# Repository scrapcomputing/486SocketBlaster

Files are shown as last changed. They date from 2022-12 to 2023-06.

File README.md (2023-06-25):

# 486SocketBlaster

486SocketBlaster is a simple voltage adapter for 486 processors. It allows you
to use a 3-volt 486 CPU on an older 5-volt-only motherboard. For example you
can use a DX4 or an Am5x86 on an old 486 motherboard that would normally only
work with 5-volt CPUs. This basically converts any 3-volt CPU to an "Overdrive".

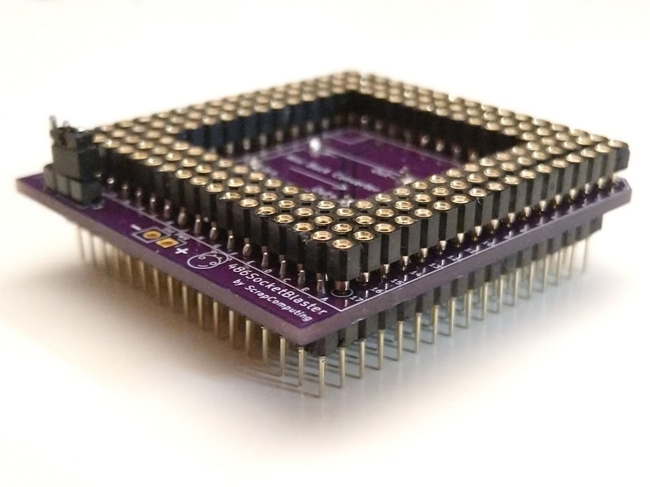
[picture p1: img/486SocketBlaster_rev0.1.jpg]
486SocketBlaster Rev0.1 on a purple PCB


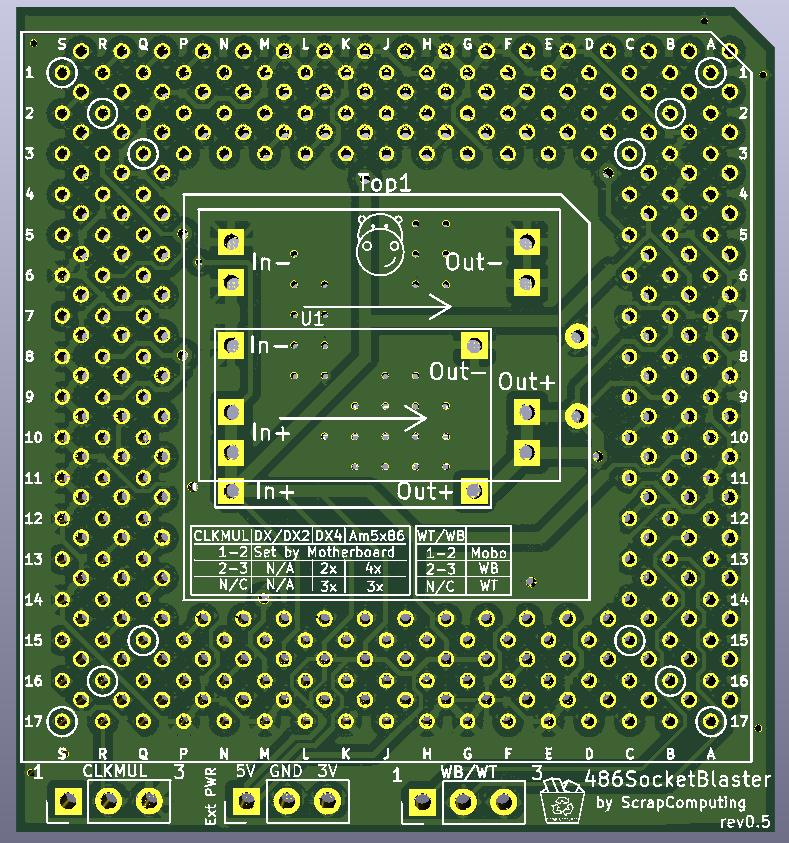
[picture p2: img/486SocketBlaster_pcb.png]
486SocketBlaster PCB


# How does it work ?

It is really simple: All CPU pins are passed through to the motherboard socket,
except for the Vcc. Those are connected to the output of a mini buck converter
that can be soldered to the 486SocketBlaster board.

# Soldering/Assembly Instructions

This board is not the easiest thing to solder, but can be done with a standard
soldering iron and some patience.
The best way to solder the headers is to start with the innermost one and work
outwards in a spiral manner alternating between the top and bottom side as
needed (see image below). This way you only work on the outside and can easily
reach all the pins.

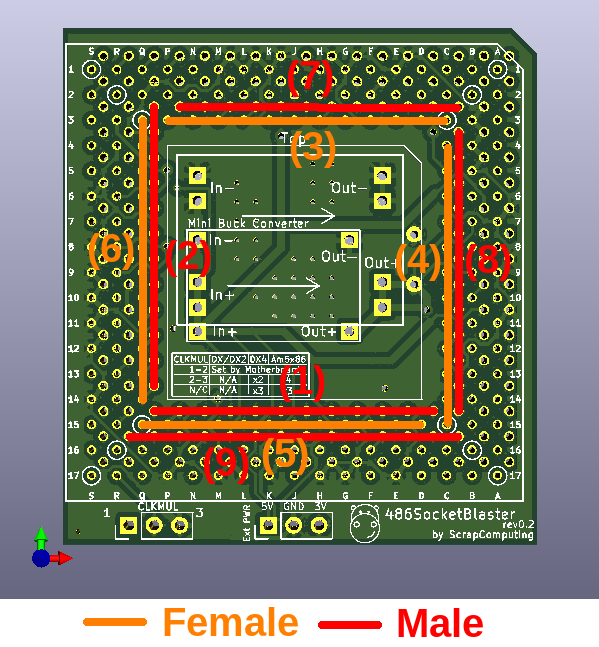
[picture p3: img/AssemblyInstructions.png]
Assembly Instructions


A desoldering gun may be useful when you accidentally clog up other holes. But
it is probably best to be very careful and avoid clogging them in the first
place. Also using flux makes it easier.

Please make sure you check the solder joints (also check for continuity) before
you add another row of headers on the same side, because the new row will
permanently block your access to the solder joints!
Desoldering a header is almost impossible even with a desoldering gun due to the
very tight hole tolerances.
So it has to be soldered correctly from the first try.

# Voltage regulator

The 486SocketBlaster can be powered by a cheap of-the-shelf buck converter, or
by an external one. The circuit board accepts two common types of small voltage
buck converters, usually found using keywords like "mini buck converter".
These are commonly rated at up to 3A of current. Given that 3-volt 486 CPUs are
usually very efficient (the DX4-100 is rated at max 3.55/5.22W typical/max) such
a regulator should be adequate in most cases.
For best stability try to source a good quality part.

If you are planning to overclock or to use a more power hungry CPU, please use an external regulation circuit plugged in to the `ExtPwr` header, or use a *very* good quality mini buck converter.

# WARNING!!!

Please make sure you know what you are doing!
Improper assembly/settings/use can damage both your precious motherboard and your precious CPU!

# Features

- External Power Header. This can be used either for monitoring the CPU voltage, or for providing power externally, either with an external power supply or an external voltage regulator.
- CLKMUL Header for selecting/overriding the CPU multiplier. This controls CPU pin `R17`. 1-2 connects it to the motherboard socket pin and 2-3 connects it to ground. This reduces the multiplier of a DX4 to 2x (66MHz) and sets the multiplier of an Am5x86 to 4x (133MHz).
- WB/WT Header for selecting/overriding Write-Back/Write-Through cache. This controls processor CPU pin `B13` (which is the `CLKMUL` pin in earlier 486 CPUs). 1-2 connects it to the motherboard socket pin, and 2-3 connects it to Vcc, which enables Write-Back.

# Bill of materials

Item                            | ##  | Description
--------------------------------|-----|--------------------------------------------------------
mini buck converter             | 1   | We support two common sizes: 22x17mm and 18x12mm. These usually have chips like MP1584, MP2307 and others
40pin SIP pin header (male)     | 5   | Single-row round pin 2.54mm pitch (male). Socket pin diameter: 0.50mm, PCB pin diameter: 0.60mm. (see photo below)
40pin SIP socket header (female)| 5   | Single-row round pin sockets, 2.54mm pitch. PCB pin diameter: 0.55mm. (see photo below) 
SMD Ceramic Capacitors          | 4   | 10uF SMD 1206, 6.3V or higher
Through-hole Capacitor          | 1   | 10uF ceramic through-hole capacitor, 6.3V or higher
3-pin header 2.54mm pitch       | 2   | (optional) Headers used for selecting the CPU Multiplier (CLKMUL) and Write-Back/Write-Through cache (WB/WT)
Jumper 2.54mm pitch             | 2   | (optional) Jumpers for the CLKMUL and WB/WT headers

Gerber files can be found in the releases: https://github.com/scrapcomputing/486SocketBlaster/releases

Please note that the headers are a very tight fit. So please make sure that you get headers of the correct pin diameter.

With the limited testing I have done so far, it seems that you need at least
one 10uF through-hole ceramic capacitor, otherwise the voltage ripple is too
high and the system can become unstable with a DX4 @ 100MHz, using a cheap
MP1584-based buck converter.

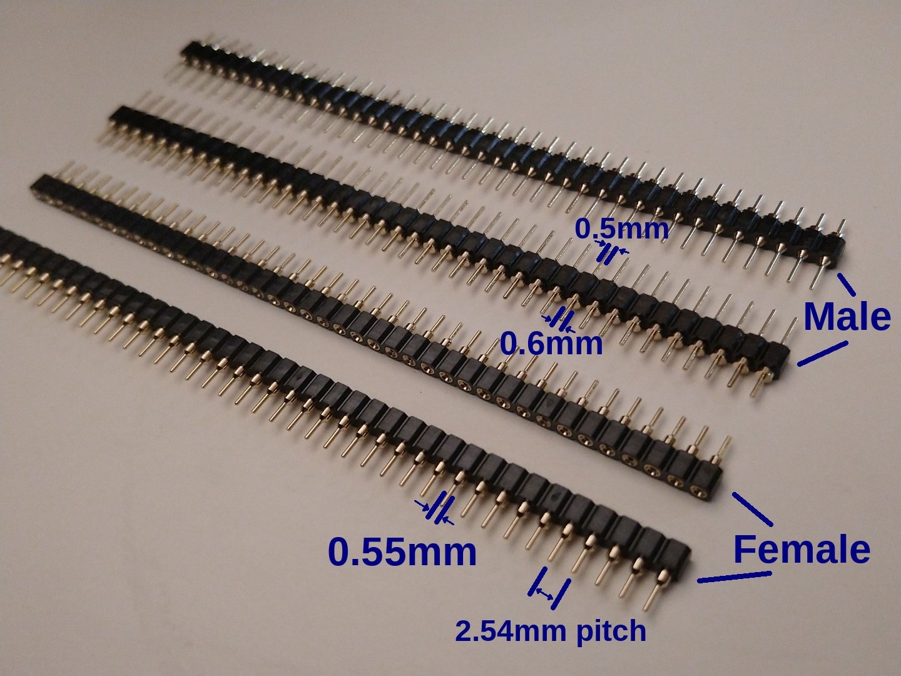
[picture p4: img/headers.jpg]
headers


# Videos featuring the 486 Socket Blaster
- Original video with rev0.1 PCB (part 1): https://www.youtube.com/watch?v=n5qlx4qKbSE
- Rev0.2 PCB and trying out smoothing caps (part 2): https://www.youtube.com/watch?v=7anzRWXtba0
- Choosing capacitor values for a 5x86 (part 3): https://www.youtube.com/watch?v=CLPSJ0jOQsU
- Detailed assembly instructions by Epictronics (rev 0.4 PCB): https://www.youtube.com/watch?v=vEpAoVE4KjU

# Changelist
- Rev 0.5 : Adds WB/WT header and fixes CLKMUL table silkscreen for am5x86.
- Rev 0.4 : Larger holes for the female headers (0.62mm instead of 0.57mm). These should fit headers with 0.55mm pin diameter.
- Rev 0.3 : Updates silk screen for larger capacitor values and fixes CLKMUL table.
- Rev 0.2 : Fixes initial revision bugs.

# List of other similar 486 adapter projects
- With an onboard voltage regulator: https://github.com/LimeProgramming/486SocketBlaster/tree/4-layer-onboard-regulator

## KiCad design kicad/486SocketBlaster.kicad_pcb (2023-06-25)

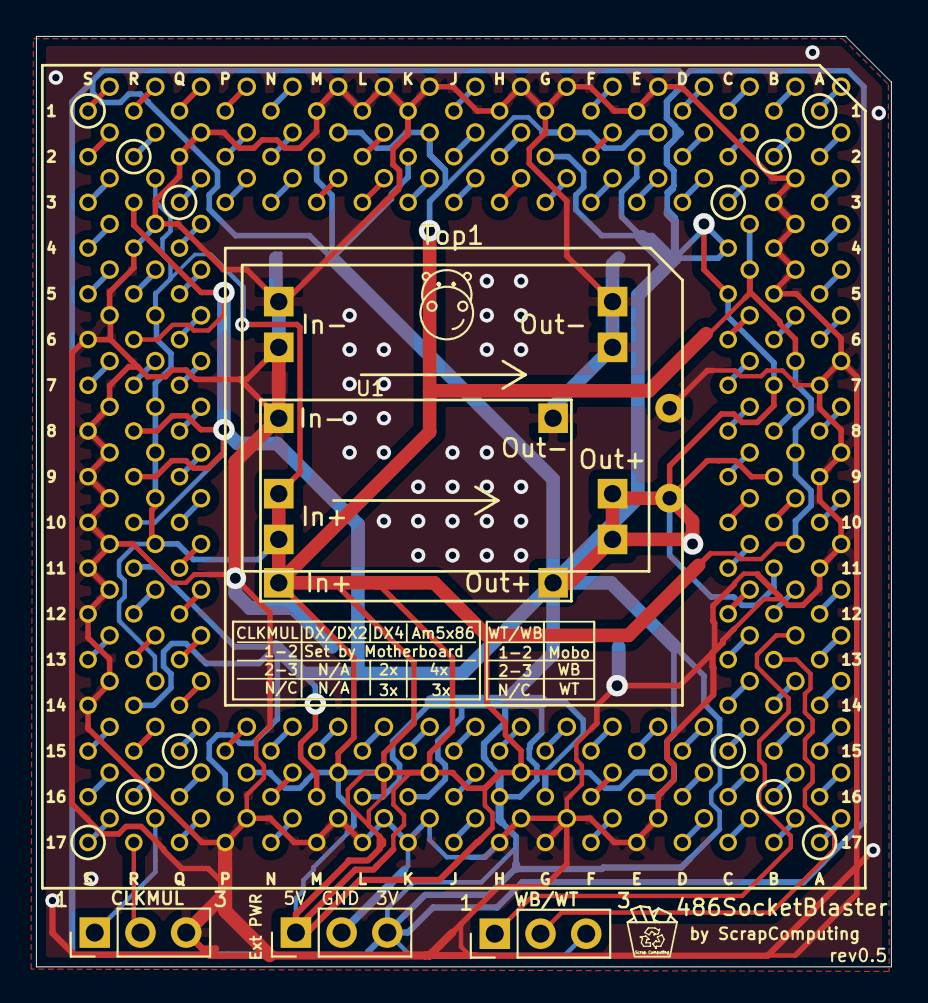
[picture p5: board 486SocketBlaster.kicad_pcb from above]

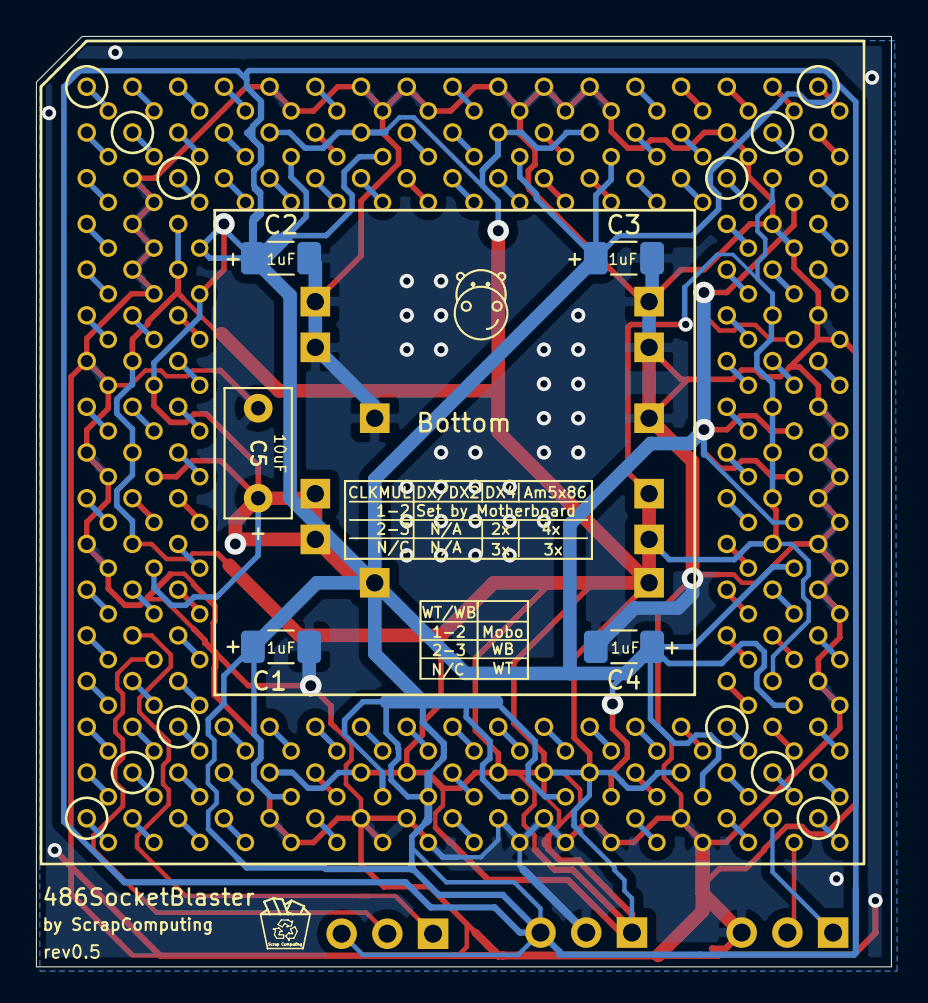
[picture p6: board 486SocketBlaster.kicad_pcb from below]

Board: 2 copper layers, 47.5 x 51.7 mm, 12 parts (5 on the bottom side), 122 nets.

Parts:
Bot1: 486; 486_168pga
C1, C2, C3, C4: 10uF; C_1206_3216Metric_Pad1.33x1.80mm_HandSolder
C5: 10uF; C_Rect_L7.0mm_W3.5mm_P5.00mm
CLKMUL: CLKMUL; PinHeader_1x03_P2.54mm_Vertical
ExtPwr1: Conn_01x03; PinHeader_1x03_P2.54mm_Vertical
J1: Conn_01x03; PinHeader_1x03_P2.54mm_Vertical
Top1: 486; 486_168pga_socket
U1: VoltageRegulator; VoltageRegulator2
U3: VoltageRegulator

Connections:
GND: Bot1.A7, Bot1.A9, Bot1.A11, Bot1.B3, Bot1.B4, Bot1.B5, Bot1.E1, Bot1.E17, Bot1.G1, Bot1.G17, Bot1.H1, Bot1.H17, Bot1.K1, Bot1.K17, Bot1.L1, Bot1.L17, Bot1.M1, Bot1.M17, Bot1.P17, Bot1.Q2, Bot1.R4, Bot1.S6, Bot1.S8, Bot1.S9, Bot1.S10, Bot1.S11, Bot1.S12, Bot1.S14, C1.2, C2.2, C3.2, C4.2, C5.2, CLKMUL.3, ExtPwr1.2, Top1.A7, Top1.A9, Top1.A11, Top1.B3, Top1.B4, Top1.B5, Top1.E1, Top1.E17, Top1.G1, Top1.G17, Top1.H1, Top1.H17, Top1.K1, Top1.K17, Top1.L1, Top1.L17, Top1.M1, Top1.M17, Top1.P17, Top1.Q2, Top1.R4, Top1.S6, Top1.S8, Top1.S9, Top1.S10, Top1.S11, Top1.S12, Top1.S14, U1.GNDin, U1.GNDout, U3.GNDin, U3.GNDout
unnamed: Bot1.A1, Top1.A1
unnamed: Bot1.A2, Top1.A2
unnamed: Bot1.A3, Top1.A3
unnamed: Bot1.A4, Top1.A4
unnamed: Bot1.A5, Top1.A5
unnamed: Bot1.A6, Top1.A6
unnamed: Bot1.A8, Top1.A8
unnamed: Bot1.A10, Top1.A10
unnamed: Bot1.A12, Top1.A12
unnamed: Bot1.A13, Top1.A13
unnamed: Bot1.A14, Top1.A14
unnamed: Bot1.A15, Top1.A15
unnamed: Bot1.A16, Top1.A16
unnamed: Bot1.A17, Top1.A17
unnamed: Bot1.B1, Top1.B1
unnamed: Bot1.B2, Top1.B2
unnamed: Bot1.B6, Top1.B6
unnamed: Bot1.B8, Top1.B8
unnamed: Bot1.B10, Top1.B10
unnamed: Bot1.B7, Bot1.B9, Bot1.B11, Bot1.C4, Bot1.C5, Bot1.E2, Bot1.E16, Bot1.G2, Bot1.G16, Bot1.H16, Bot1.K2, Bot1.K16, Bot1.L16, Bot1.M2, Bot1.M16, Bot1.P16, Bot1.R3, Bot1.R6, Bot1.R8, Bot1.R9, Bot1.R10, Bot1.R11, Bot1.R14, ExtPwr1.1, U1.Vin, U3.Vin
unnamed: Bot1.B12, Top1.B12
unnamed: Bot1.B13, J1.1
unnamed: Bot1.B14, Top1.B14
unnamed: Bot1.B15, Top1.B15
unnamed: Bot1.B16, Top1.B16
unnamed: Bot1.B17, Top1.B17
unnamed: Bot1.C1, Top1.C1
unnamed: Bot1.C2, Top1.C2
unnamed: Bot1.C3, Top1.C3
unnamed: Bot1.C6, Top1.C6
unnamed: Bot1.C7, Top1.C7
unnamed: Bot1.C8, Top1.C8
unnamed: Bot1.C9, Top1.C9
unnamed: Bot1.C10, Top1.C10
unnamed: Bot1.C11, Top1.C11
unnamed: Bot1.C12, Top1.C12
unnamed: Bot1.C13, Top1.C13
unnamed: Bot1.C14, Top1.C14
unnamed: Bot1.C15, Top1.C15
unnamed: Bot1.C16, Top1.C16
unnamed: Bot1.C17, Top1.C17
unnamed: Bot1.D1, Top1.D1
unnamed: Bot1.D2, Top1.D2
unnamed: Bot1.D3, Top1.D3
unnamed: Bot1.D15, Top1.D15
unnamed: Bot1.D16, Top1.D16
unnamed: Bot1.D17, Top1.D17
unnamed: Bot1.E3, Top1.E3
unnamed: Bot1.E15, Top1.E15
unnamed: Bot1.F1, Top1.F1
unnamed: Bot1.F2, Top1.F2
unnamed: Bot1.F3, Top1.F3
unnamed: Bot1.F15, Top1.F15
unnamed: Bot1.F16, Top1.F16
unnamed: Bot1.F17, Top1.F17
unnamed: Bot1.G3, Top1.G3
unnamed: Bot1.G15, Top1.G15
unnamed: Bot1.H2, Top1.H2
unnamed: Bot1.H3, Top1.H3
unnamed: Bot1.H15, Top1.H15
unnamed: Bot1.J1, Top1.J1
unnamed: Bot1.J2, Top1.J2
unnamed: Bot1.J3, Top1.J3
unnamed: Bot1.J15, Top1.J15
unnamed: Bot1.J16, Top1.J16
unnamed: Bot1.J17, Top1.J17
unnamed: Bot1.K3, Top1.K3
unnamed: Bot1.K15, Top1.K15
unnamed: Bot1.L2, Top1.L2
unnamed: Bot1.L3, Top1.L3
unnamed: Bot1.L15, Top1.L15
unnamed: Bot1.M3, Top1.M3
unnamed: Bot1.M15, Top1.M15
unnamed: Bot1.N1, Top1.N1
unnamed: Bot1.N2, Top1.N2
unnamed: Bot1.N3, Top1.N3
unnamed: Bot1.N15, Top1.N15
unnamed: Bot1.N16, Top1.N16
unnamed: Bot1.N17, Top1.N17
unnamed: Bot1.P1, Top1.P1
unnamed: Bot1.P2, Top1.P2
unnamed: Bot1.P3, Top1.P3
unnamed: Bot1.P15, Top1.P15
unnamed: Bot1.Q1, Top1.Q1
unnamed: Bot1.Q3, Top1.Q3
unnamed: Bot1.Q4, Top1.Q4
unnamed: Bot1.Q5, Top1.Q5
unnamed: Bot1.Q6, Top1.Q6
unnamed: Bot1.Q7, Top1.Q7
unnamed: Bot1.Q8, Top1.Q8
unnamed: Bot1.Q9, Top1.Q9
unnamed: Bot1.Q10, Top1.Q10
unnamed: Bot1.Q11, Top1.Q11
unnamed: Bot1.Q12, Top1.Q12
unnamed: Bot1.Q13, Top1.Q13
unnamed: Bot1.Q14, Top1.Q14
unnamed: Bot1.Q15, Top1.Q15
unnamed: Bot1.Q16, Top1.Q16
unnamed: Bot1.Q17, Top1.Q17
unnamed: Bot1.R1, Top1.R1
unnamed: Bot1.R2, Top1.R2
unnamed: Bot1.R5, Top1.R5
unnamed: Bot1.R7, Top1.R7
unnamed: Bot1.R12, Top1.R12
unnamed: Bot1.R13, Top1.R13
unnamed: Bot1.R15, Top1.R15
unnamed: Bot1.R16, Top1.R16
unnamed: Bot1.R17, CLKMUL.1
unnamed: Bot1.S1, Top1.S1
unnamed: Bot1.S2, Top1.S2
unnamed: Bot1.S3, Top1.S3
unnamed: Bot1.S4, Top1.S4
unnamed: Bot1.S5, Top1.S5
unnamed: Bot1.S7, Top1.S7
unnamed: Bot1.S13, Top1.S13
unnamed: Bot1.S15, Top1.S15
unnamed: Bot1.S16, Top1.S16
unnamed: Bot1.S17, Top1.S17
unnamed: C1.1, C2.1, C3.1, C4.1, C5.1, ExtPwr1.3, J1.3, Top1.B7, Top1.B9, Top1.B11, Top1.C4, Top1.C5, Top1.E2, Top1.E16, Top1.G2, Top1.G16, Top1.H16, Top1.K2, Top1.K16, Top1.L16, Top1.M2, Top1.M16, Top1.P16, Top1.R3, Top1.R6, Top1.R8, Top1.R9, Top1.R10, Top1.R11, Top1.R14, U1.Vout, U3.Vout
unnamed: CLKMUL.2, Top1.R17
unnamed: J1.2, Top1.B13

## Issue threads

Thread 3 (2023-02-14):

Source for pin headers

olkang, 2023-02-14:
Hi ScrapComputing,

I couldn't find another way to contact you with a question that wasn't youtube. I'm trying to source the pin headers but my google search skills must be week. Could you possibly link to a supplier's product page for them?

Also thanks again for all your work and have you thought about setting up a patreon page?

scrapcomputing, 2023-02-14:
Hi olkang,

I think I got mine on ebay long time ago, but I just checked and such headers show up on both ebay and amazon. Just use keywords like "round headers 2.54mm" and you will find them (you can also find them in male/female pairs). Most sellers list images with detailed dimensions, so just make sure that the male header pin diameter is 0.50mm at the bottom (that will face the motherboard socket) and 0.60mm at the top (this will get soldered onto the PCB, the drill hole is 0.67mm).
So here is the thing about the female header. In the instructions I list the female header diameter as as 0.50mm (this is what was shown on the ebay seller's listing), but I just measured it with my calipers and it measures 0.54mm, so it must be a 0.55mm part, which is the most common size from what I can see. The drill hole size in the PCB is 0.57mm so there is a chance that the 0.55mm part won't fit if the tolerance is too high.

So here is what I will do. I will increase the hole size to 0.62mm so that they will fit the 0.55mm since this is the most common pin diameter for the female headers. Stay tuned for an updated PCB.

scrapcomputing, 2023-02-14:
I updated the PCB, please check out rev 0.4. This revision should fit nicely female headers with a 0.55mm pin diameter.

olkang, 2023-02-15:
Very cool, I've got what I believe are the correct pin sets on order through alieexpress. Once they come in I'll get a round of boards made.

Thanks again!

Closed 2023-05-29.

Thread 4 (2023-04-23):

Gerber files

rkurbatov, 2023-04-23:
Hi! Thank you for your work, I definitely want to give it a try.

I have some soldering experience but not a PCB development so never used KiCAD. Could you please provide Gerber files as it's the simplest way to order these boards somewhere like PCBWay or JLC PCB? Thanks in advance.

And what is the thickness of the board? I probably missed that in the video.

scrapcomputing, 2023-04-23:
Hi,
The gerber files can be found in the release section: https://github.com/scrapcomputing/486SocketBlaster/releases
I should probably add a link to them in the readme text.

Regarding the PCB thickness, it shouldn't matter too much. My PCBs are 1.6mm thick and I think you can go a little bit thicker or thinner and there should be no issue at all.

Closed 2023-04-23.

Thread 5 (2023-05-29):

Allow for usage of available 168-pin sockets

megatog615, 2023-05-29:
It is possible to purchase 168-pin sockets [online](https://www.peconnectors.com/sockets-pga-cpu-and-memory/hws6934/). Perhaps the pcb could be redesigned to make use of them as a way to make the assembly easier? I have already considered buying one to use as a guide to hold pins in place for soldering, but I was wondering if it would not just be better to use them in the design.

scrapcomputing, 2023-05-29:
We can't use a socket with the current design because it makes it impossible to solder it with a soldering iron: If we solder the socket then we can't solder the pins because they will be covered by the socket. If instead we solder the bottom pins first, then the pins will cover the pads se we won't be able to solder the socket.

So using a socket would require a complete redesign of the board, perhaps splitting it into two sections, or would require some fancy soldering techniques.

Closed 2023-05-29.

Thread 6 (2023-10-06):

Need to buy it.

dirsors, 2023-10-06:
Hi. I'm from Brazil and I would like if you can build one of these and sell it for me. I would buy it from you. Thank you!

scrapcomputing, 2023-10-07:
Hi,
Sorry but I can't sell them. I am not a professional, so it takes me a very long time to make these boards, and the result is not of the best quality.
You can order the boards from the PCB manufacturer of your choice by just uploading the zipped gerber files (found in the release section), and you can easily find the rest of the components online. If you don't have the soldering skills or equipment you may ask your local cellphone/electronics repair shop to solder one for you.
Thanks!

Closed 2023-10-07.

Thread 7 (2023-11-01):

Gerber RS 274x format

dirsors, 2023-11-01:
I would like to ask something very important so that the company I hired can build the boards: The project available in Gerber RS-274X Format. Thank you so much!

scrapcomputing, 2023-11-01:
Hi, I am not 100% sure, but I think the gerber files should be compatible with the RS-274X format. Most board manufacturers should be fine with the gerber files in the releases.
Have they already rejected the gerber files? And if so, could you please share the reason why they rejected them?

dirsors, 2023-11-01:
They didn't tell me why, they simply said it needs to be in Gerber RS-274X format. Can you export in this format? I would appreciate it.

scrapcomputing, 2023-11-01:
There is not much information about this online and from what I can tell kicad is already generating RS-274X. But perhaps your fab does not like the X2 extensions? I generated the gereber files without these X2 extensions. Could you try these out (see attached)
[486SocketBlaster_rev0.5_gerbers_noX2.zip](https://github.com/scrapcomputing/486SocketBlaster/files/13232421/486SocketBlaster_rev0.5_gerbers_noX2.zip)
?

dirsors, 2023-11-01:
Thank you. Tomorrow is holiday here in Brazil and the fab will open only on friday, 03. I'll give a return as soon as possible.

wrljet, 2023-11-01:
Novice comment here.  What FAB wouldn't accept/handle all formats?

dirsors, 2023-11-01:
Look what the fab said:
"Kicad não abrimos, vc precisa enviar os arquivos em Gerber no formato RS 274x"
"We don't open Kicad, you need to send the files in Gerber in the format RS 274x"
The company is https://www.micropress.com.br/

scrapcomputing, 2023-11-02:
Ah so if I understand correctly you probably sent them the source files (kicad) instead of the gerber files. The gerber files are listed in the releases and are include "_gerbers_" in the filename, like: https://github.com/scrapcomputing/486SocketBlaster/releases/download/rev0.5/486SocketBlaster_rev0.5_gerbers.zip

dirsors, 2023-11-02:
Oh, you're right. I didn't check the "Release" section, but only the kicad folder at master branch. I think they'll accept it.

scrapcomputing, 2023-11-02:
Yeah, I think they should work fine. Glad we figured out what the issue was.

Closed 2023-11-02.

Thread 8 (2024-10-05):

Fault finding guide

RetroErik, 2024-10-05:
Hi, and thank for the 486SocketBlaster project.

I have tried making it. Here is a video about it. https://youtu.be/YV4V_aUYyPI
Status is that three are now working, and 4 are not.

Could you point me in a direction on how to find the faults? I believe the problem is bad soldering or short circuit. Maybe this is impossible to fix. Maybe i could try putting the 486 Socket Blaster in the own at 250 digress Celcuis?

scrapcomputing, 2024-10-06:
Thanks for the great video!

Soldering is indeed quite tricky because there is no room for error. What I did to avoid faults was to inspect closely each solder joint right after I solder one row, and fix any issues right away. Also using leaded solder + flux is probably the best option.

You may also check for continuity with the other side, as almost all pins are passed through, except for the power ones and the ones that connect to the headers (for multiplier etc.), though this can become very time consuming.

Not sure how you would fix a bad one. Wouldn't 250 degrees melt the plastics too? I would be curious to know if that fixes it :)

RetroErik, 2024-10-07:
I tried baking it. Only made it worse. Now the PSU shuts down immediately after power on.
But it helped adjusting the pins so that it more easily can go into the socket.

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

scrapcomputing, 2024-10-07:
Good to know :)

I am experimenting with a new design that should be a lot easier to put together and debug. I will keep you posted.

scrapcomputing, 2024-10-07:
You can't use such sockets in the current design because there is no way to solder the pins of the other.

Regarding the jumper for selecting the internal/external voltage regulator, this is not easy to do because it requires routing the voltage wires all the way to the outside and back inside again.

Selecting the FSB frequency is not possible, this is done by the motherboard. But I am planning on adding a pin for the Throttle Blaster which allows you to dial in the CPU performance.

RetroErik, 2024-10-07:
Or course one cannot change FSB, but the frequence the CPU is running, or maybe the multiplier? E.x. 2.5x, 3x and 3.5x

Is not the Throttle Blaster only for reduce speed?, can it be used to "dial -in" frequency or clock multiplier?

scrapcomputing, 2024-10-07:
You can only change the multiplier for DX4 an 5x86 just like with the CLKMUL jumper. These CPUs don't allow you to change it any further.

Yes, the Throttle Blaster will only reduce the speed. So what you can do is set the CPU to run at maximum speed, and then use the Throttle Blaster to dial in any "frequency" you want for speed-sensitive games. This works by doing pulse-width modulation on the STPCLK pin, which has a similar effect to reducing the frequency.

RetroErik, 2024-10-07:
Thanks for the info.
I follow you on Github and YouTube, looking forward to see it.
If you need help beta testing or something just reach out.

RetroErik, 2024-10-27:
Is there a way to contact you?
Could you please send me an email at hageseter@mail.com?
PCWway has offered me to produce a 486SocketBlaster for free if i make a video.

scrapcomputing, 2024-11-03:
I sent you an email at the email you provided a couple of days back, but it might have landed on your junk folder.

By the way I have been experimenting with a new design, which is much easier to assemble. I will make it available shortly.

RetroErik, 2024-11-03:
I just saw your latest video. Again you have done a superb job.
I have not received any email I have looked though my emails and cannot find anything from you. Does it contain some text i can search for? I tried searching email for the text 486SocketBlaster, but are only finding email coming from github.

scrapcomputing, 2024-11-03:
Strange, it was sent one week ago and it didn't bounce. Anyway could you try sending an email to me at scrapcomputing at gmail.com ?

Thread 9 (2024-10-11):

After upgrading my CPU from DX2-66 to 3.3 V DX4 the PC only sees 500MB Disk

RetroErik, 2024-10-11:
Last week i upgraded my Compaq 524 CDS from DX2-66 to a AMD 5x86. The machine worked fine, but the PC only sees 500MB of my CF card. First i thought it just was a freak event, but today i am upgrading a IBM PS/1 from DX2-66 to a AMD DX4-100 and i have the exact same problem with my CF Card. The CF card is 8GB.
Fdisk only sees  528MB, and BIOS the same. There is no option in the BIOS to set other sizes.
On the Compaq CDS the BIOS had options to set pother sizes, but it would reset to 500MB on every boot.

scrapcomputing, 2024-10-11:
Interesting... Could you check if all address lines have continuity through the adapter ? If there is a limit at around 500MB, then perhaps some of the address pins some continuity issue? I would check all high-order address bits just in case, or try with a different adapter.

I doubt it would break LBA. All pins are passed through except for the ones for power.

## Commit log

2022-12-30 Rev 0.2: Fixes initial revision bugs
    - Supports second type of voltage regulator
    - Hole pads are now a little larger
    [486SocketBlaster.kicad_pcb, 486SocketBlaster.sch]
2022-12-31 README: Improved assembly instructions
2023-01-09 Fixed CPUMUL multipliers table and changed capacitor values to 10uF
    [486SocketBlaster.kicad_pcb, 486SocketBlaster.sch]
2023-01-09 Updated capacitor values in README
2023-02-14 Larger holes (and pads) for 0.55mm female pin headers.
    [486SocketBlaster.kicad_pcb, 486SocketBlaster.sch]
2023-04-23 Added link to gerber files
2023-06-25 Rev 0.5: Add WB/WT header and fix CLKMUL table silkscreen for am5x86
    [486SocketBlaster.kicad_pcb, 486SocketBlaster.sch]
